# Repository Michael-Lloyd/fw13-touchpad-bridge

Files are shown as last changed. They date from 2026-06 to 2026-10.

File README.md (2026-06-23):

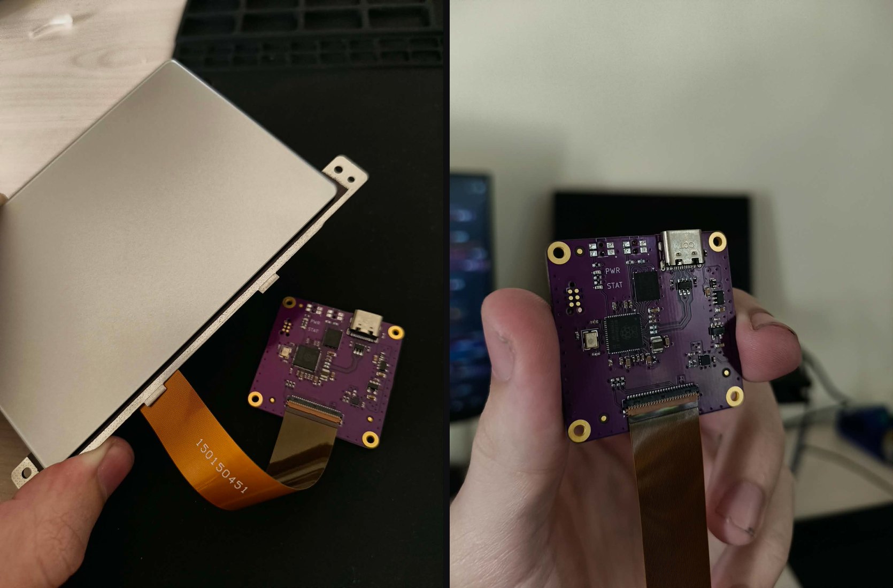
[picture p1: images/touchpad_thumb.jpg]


# Framework 13 Touchpad to USB bridge

Demo video can be found [here](https://youtu.be/qEcvwA03GHM?si=J2vbeN7p9iwUP8ut)

## Hardware files

You can find all of the hardware files under `hardware/` including the the gerbers, drill files and CSV that can be imported into Digikey carts. 

I've done everything in KiCAD, which is free on most systems. 

## Firmware 

The firmware is under `firmware/` and can be built using the Raspberry Pi pico-sdk toolchain. 

If you have any questions or want to talk to me about this project, you can contact me using one of the methods on my website at [micl.dev](https://micl.dev)

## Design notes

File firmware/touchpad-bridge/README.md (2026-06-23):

# Touchpad bridge/adapter firmware

This contains the firmware for the framework 13 touchpad bridge/adapter. The touchpad uses a PixArt PCT3854 HID-over-I2C IC, the report descriptors and feature reports can be passed transparently (including the Microsoft certification blob) unchanged. 

To use this firmware you will need access to the BC-TPI-* board and an appropriately selected 0.3mm pitch ribbon FPC cable to use with it. 

## Building

Requires the pico SDK, an appropriate compile (i.e `arm-none-eabi-gcc`), `cmake`, `ninja` and `picotool` for interacting with the microcontroller. 

To build the binary: 

```bash
# Make sure PICO_SDK_PATH is set 
cmake -B build -G Ninja 
cmake --build build
```

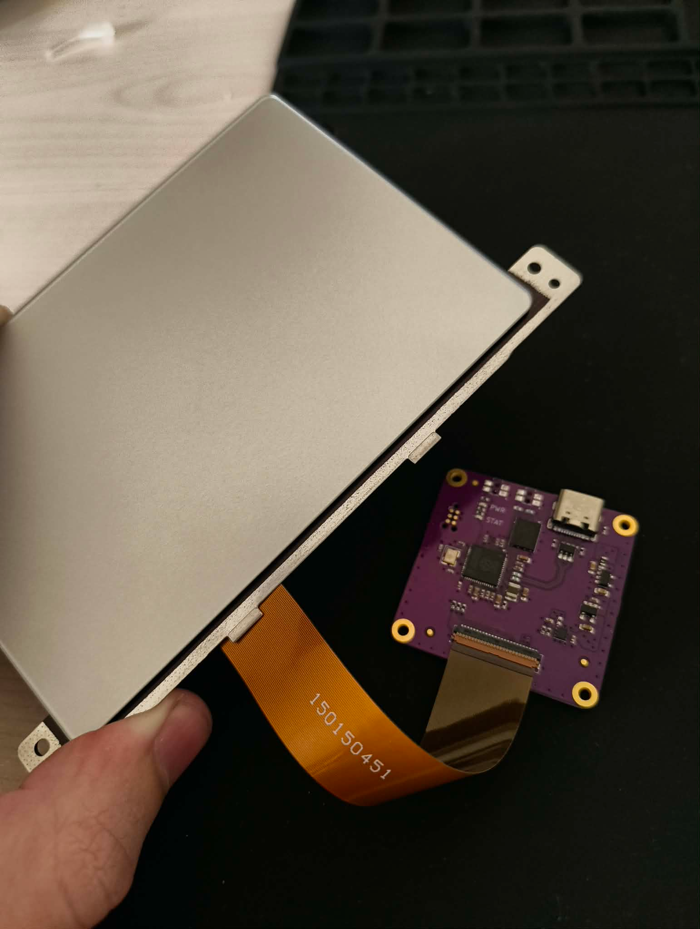
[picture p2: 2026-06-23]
images/touchpad_plugged_in.png

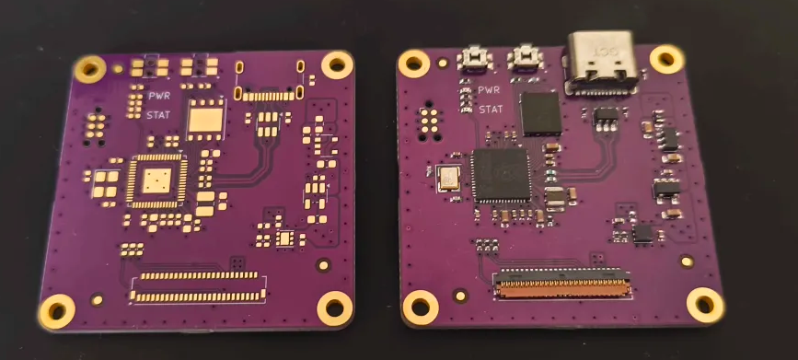
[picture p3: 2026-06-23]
images/gallery17.png

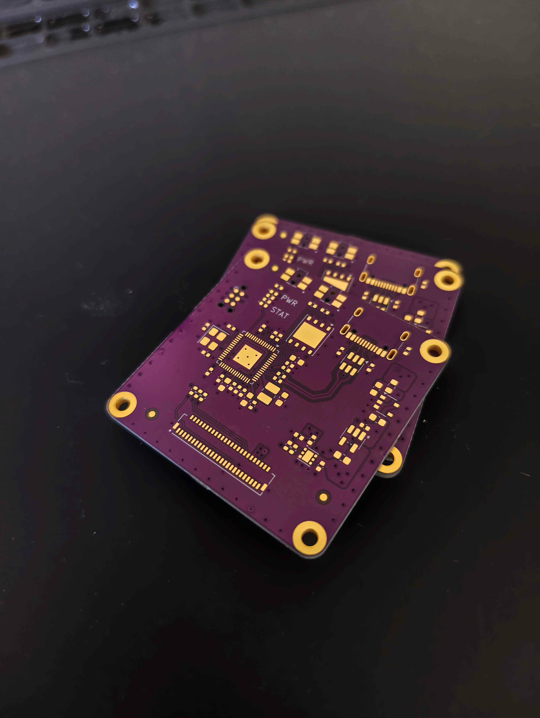
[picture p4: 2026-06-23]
images/gallery18.png

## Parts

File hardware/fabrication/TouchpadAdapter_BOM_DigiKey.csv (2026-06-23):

Digi-Key Part Number | Customer Reference | Quantity
490-10698-1-ND | TP-BRIDGE C1, C5, C7, C8, C9, C10, C11, C13, C14, C15, C16 | 11
490-GRM188Z71A475KE15JCT-ND | TP-BRIDGE C2, C3, C4, C6, C20 | 5
490-5888-1-ND | TP-BRIDGE C17, C18 | 2
490-10017-1-ND | TP-BRIDGE C19, C23, C24 | 3
490-14409-1-ND | TP-BRIDGE C21, C22 | 2
732-13422-1-ND | TP-BRIDGE D1 | 1
732-13424-1-ND | TP-BRIDGE D2 | 1
F5760CT-ND | TP-BRIDGE F1 | 1
490-4002-1-ND | TP-BRIDGE FB1 | 1
445-TFM252012ALVA3R3MTAACT-ND | TP-BRIDGE L1 | 1
2151-RH100-12.000-12-1010-X-TR-NS2CT-ND | TP-BRIDGE Y1 | 1
2019-RK73H1ERTTP1002FCT-ND | TP-BRIDGE R1 | 1
P2.20KLCT-ND | TP-BRIDGE R2, R11 | 2
P4.70KLCT-ND | TP-BRIDGE R3 | 1
P1.00KLCT-ND | TP-BRIDGE R4, R10, R15, R16 | 4
P33.0LCT-ND | TP-BRIDGE R5 | 1
2019-RK73H1ETTP27R0FCT-ND | TP-BRIDGE R6, R7 | 2
P5.10KLCT-ND | TP-BRIDGE R8, R9 | 2
P0.0JCT-ND | TP-BRIDGE R12 | 1
541-100KLCT-ND | TP-BRIDGE R13, R14 | 2
P16765CT-ND | TP-BRIDGE SW1, SW2 | 2
H125806CT-ND | TP-BRIDGE J1 | 1
2073-USB4105-GF-ACT-ND | TP-BRIDGE J3 | 1
2648-SC1509-A4CT-ND | TP-BRIDGE U1 | 1
256-W25Q128JVPIQ-TUBE-ND | TP-BRIDGE U2 | 1
296-TPS7A2033PDBVRCT-ND | TP-BRIDGE U3 | 1
497-11882-1-ND | TP-BRIDGE U4 | 1
NCP361SNT1GOSCT-ND | TP-BRIDGE U5 | 1
296-TLV75901PDRVRCT-ND | TP-BRIDGE U6 | 1
WM21809-ND | TP-BRIDGE CABLE | 1

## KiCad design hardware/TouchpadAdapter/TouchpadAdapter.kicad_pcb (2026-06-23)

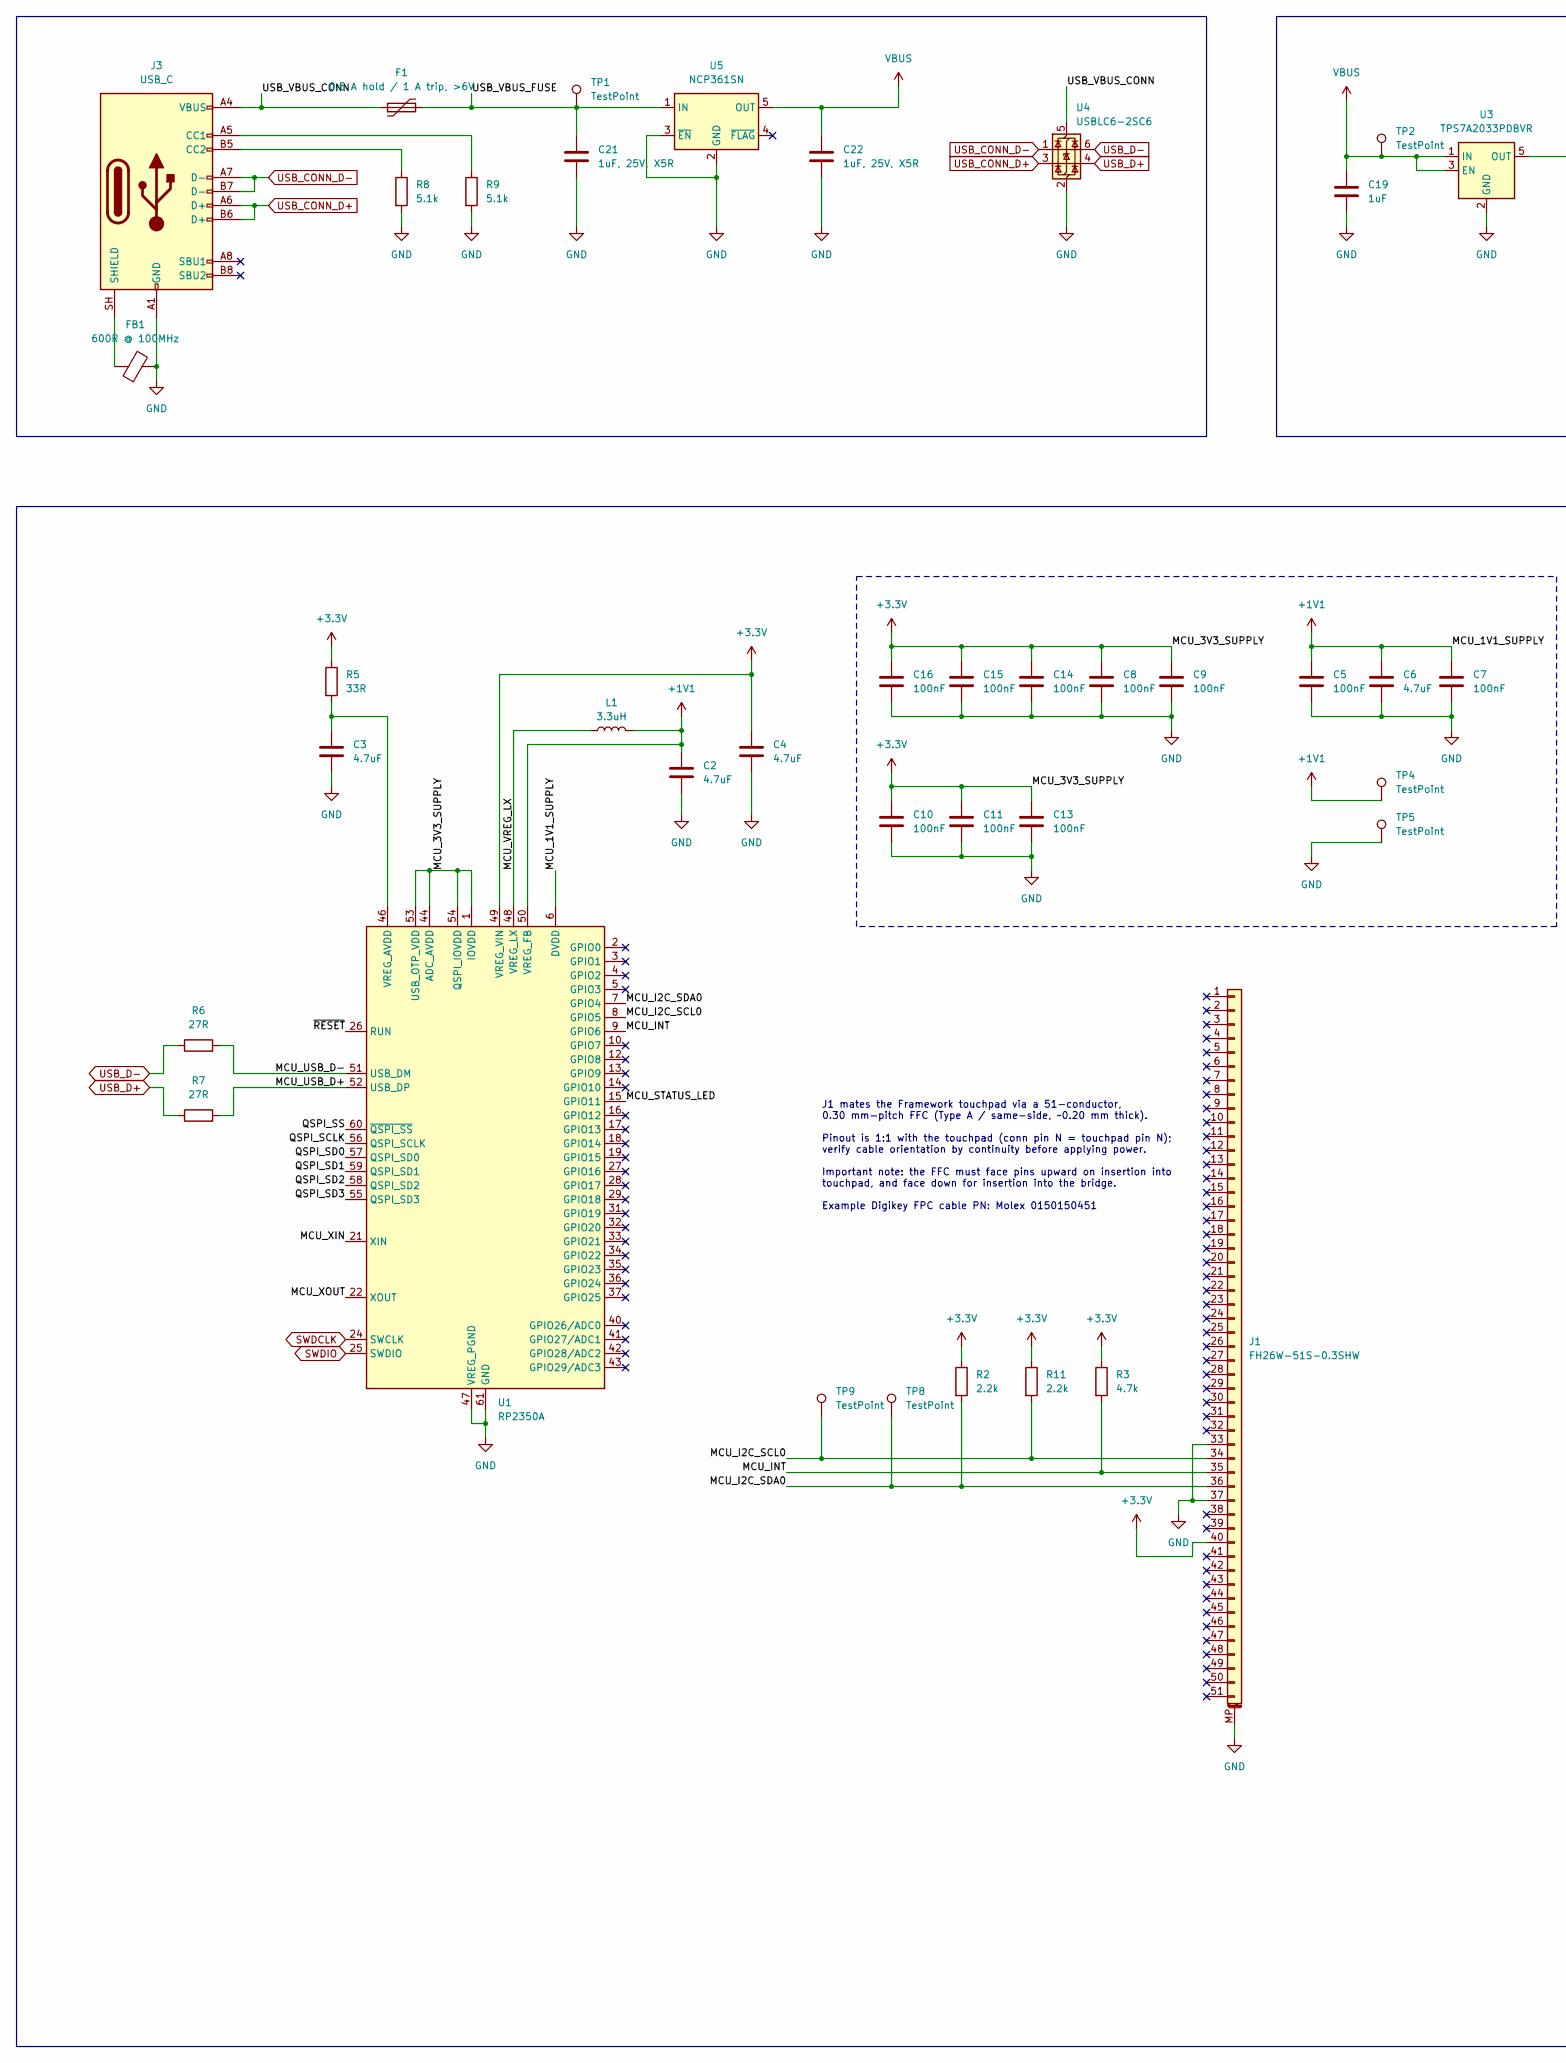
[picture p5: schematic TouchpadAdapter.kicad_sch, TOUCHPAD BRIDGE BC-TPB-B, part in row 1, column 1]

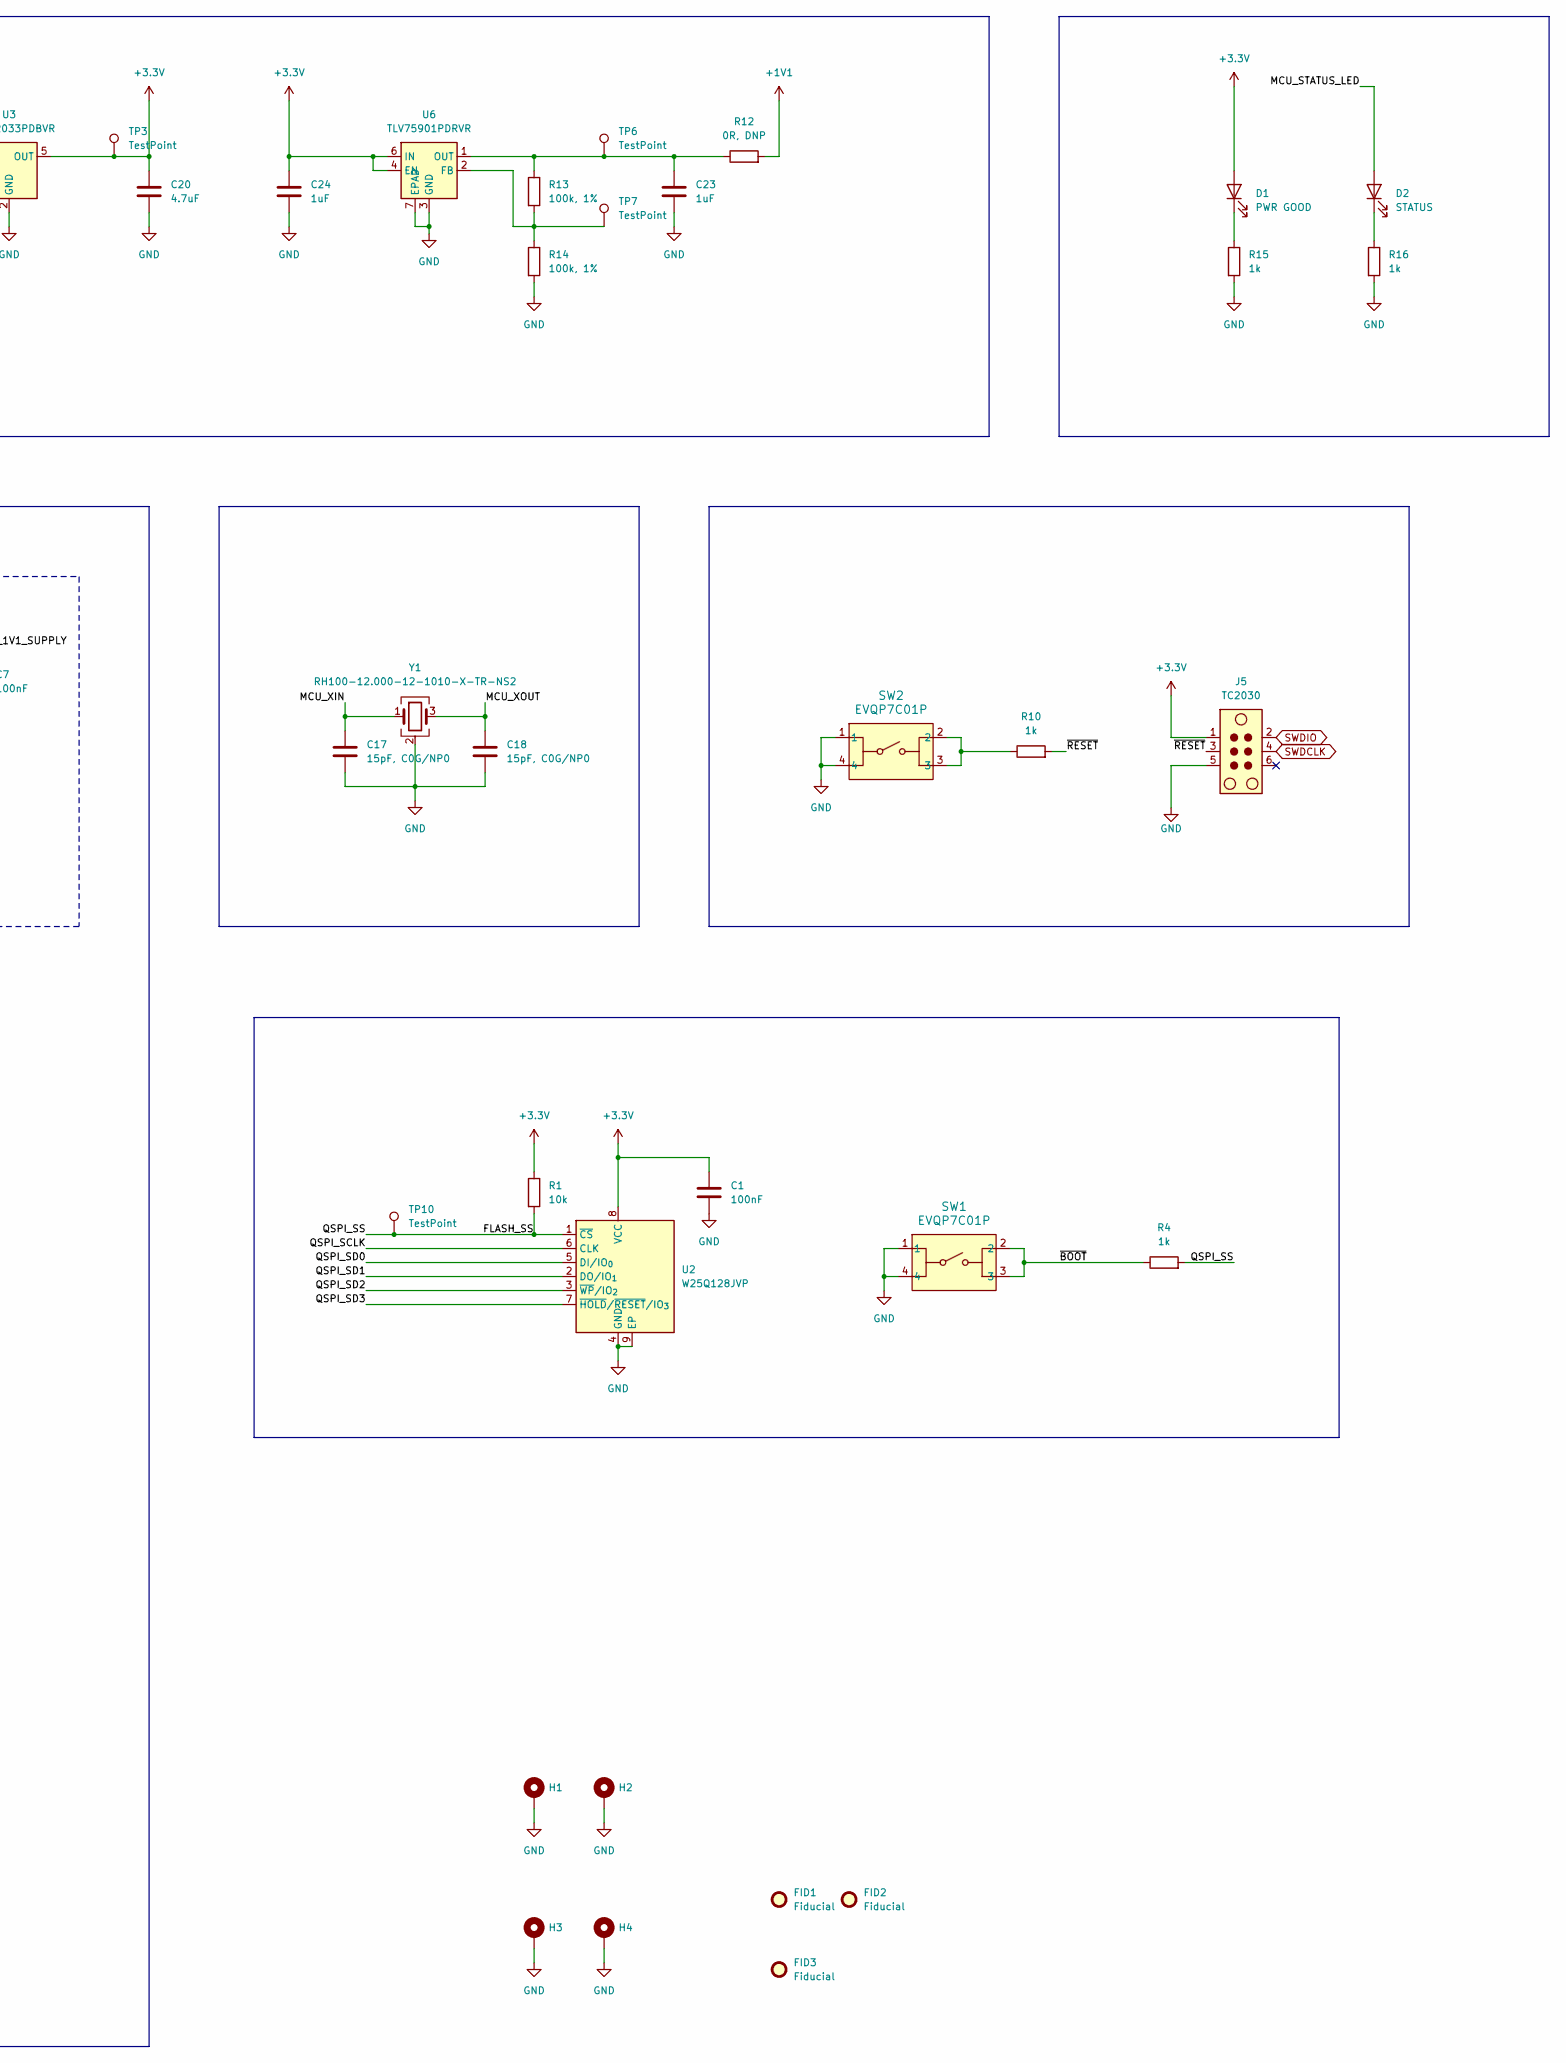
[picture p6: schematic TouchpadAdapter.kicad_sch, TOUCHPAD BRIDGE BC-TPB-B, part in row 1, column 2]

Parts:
C1, C5, C7, C8, C9, C10, C11, C13, C14, C15, C16: 100nF; C_0402_1005Metric; Digikey_MPN GRM155R71E104KE14D
C2, C3, C4, C6, C20: 4.7uF; C_0603_1608Metric; Digikey_MPN GRM188Z71A475KE15J
C17, C18: 15pF, C0G/NP0; C_0402_1005Metric; Digikey_MPN GRM1555C1H150JA01D
C19, C23, C24: 1uF; C_0402_1005Metric; Digikey_MPN GRM155R61E105KA12D
C21, C22: 1uF, 25V, X5R; C_0603_1608Metric; Digikey_MPN GRT188R71E105KE13J
D1: PWR GOOD; LED_0402_1005Metric; Digikey_MPN 150040RS73220
D2: STATUS; LED_0402_1005Metric; Digikey_MPN 150040YS73220
F1: 0.5 A hold / 1 A trip, >6V; R_0603_1608Metric; Digikey_MPN 0603L050SLYR
FB1: 600R @ 100MHz; R_0402_1005Metric; Digikey_MPN BLM15HD601SN1D
FID1, FID2, FID3: Fiducial; Fiducial_1mm_Mask2mm
H1, H2, H3, H4: MountingHole_Pad; MountingHole_2.2mm_M2_Pad
J1: FH26W-51S-0.3SHW; FH26W-51S-0.3SHW60; Digikey_MPN FH26W-51S-0.3SHW(60)
J3: USB_C; USB_C_Receptacle_GCT_USB4105-xx-A_16P_TopMnt_Horizontal
J5: TC2030; Tag-Connect_TC2030-IDC-NL_2x03_P1.27mm_Vertical; Digikey_MPN TC2030-IDC-NL
L1: 3.3uH; L_1008_2520Metric; Digikey_MPN TFM252012ALVA3R3MTAA
R1: 10k; R_0402_1005Metric; Digikey_MPN ERJ-2RKF1002X
R2, R11: 2.2k; R_0402_1005Metric; Digikey_MPN ERJ-2RKF2201X
R3: 4.7k; R_0402_1005Metric; Digikey_MPN ERJ-2RKF4701X
R4, R10, R15, R16: 1k; R_0402_1005Metric; Digikey_MPN ERJ-2RKF1001X
R5: 33R; R_0402_1005Metric; Digikey_MPN ERJ-2RKF33R0X
R6, R7: 27R; R_0402_1005Metric; Digikey_MPN ERJ-2RKF27R0X
R8, R9: 5.1k; R_0402_1005Metric; Digikey_MPN ERJ-2RKF5101X
R12: 0R, DNP; R_0402_1005Metric; Digikey_MPN ERJ-2GE0R00X
R13, R14: 100k, 1%; R_0402_1005Metric; Digikey_MPN CRCW0402100KFKED
SW1, SW2: EVQP7C01P; Digikey_MPN EVQ-P7C01P
TP1, TP2, TP3, TP4, TP5, TP6, TP7, TP8, TP9, TP10: TestPoint; TestPoint_Pad_D0.5mm
U1: RP2350A; QFN-60-1EP_7x7mm_P0.4mm_EP3.4x3.4mm; Digikey_MPN RP2350A
U2: W25Q128JVP; WSON-8-1EP_6x5mm_P1.27mm_EP3.4x4.3mm; Digikey_MPN W25Q128JVPIQ
U3: TPS7A2033PDBVR; SOT-23-5; Digikey_MPN TPS7A2033PDBVR
U4: USBLC6-2SC6; SOT-23-6; Digikey_MPN USBLC6-2SC6Y
U5: NCP361SN; TSOP-5_1.65x3.05mm_P0.95mm; Digikey_MPN NCP361SNT1G
U6: TLV75901PDRVR; WSON-6-1EP_2x2mm_P0.65mm_EP1x1.6mm; Digikey_MPN TLV75901PDRVR
Y1: RH100-12.000-12-1010-X-TR-NS2; Crystal_SMD_3225-4Pin_3.2x2.5mm; Digikey_MPN RH100-12.000-12-1010-X-TR-NS2

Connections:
+1V1: C2.1, C5.1, C6.1, C7.1, L1.2, R12.2, TP4.1 (1_1), U1.6 (DVDD), U1.23 (DVDD), U1.39 (DVDD), U1.50 (VREG_FB)
+3.3V: C1.1, C4.1, C8.1, C9.1, C10.1, C11.1, C13.1, C14.1, C15.1, C16.1, C20.1, C24.1, D1.2 (A), J1.40, J5.1, R1.1, R2.1, R3.1, R5.1, R11.1, TP3.1 (1_1), U1.1 (IOVDD), U1.11 (IOVDD), U1.20 (IOVDD), U1.30 (IOVDD), U1.38 (IOVDD), U1.44 (ADC_AVDD), U1.45 (IOVDD), U1.49 (VREG_VIN), U1.53 (USB_OTP_VDD), U1.54 (QSPI_IOVDD), U2.8 (VCC), U3.5 (OUT), U6.4 (EN), U6.6 (IN)
/FLASH_SS: R1.2, R4.2, TP10.1 (1_1), U1.60 (~QSPI_SS), U2.1 (~CS)
/MCU_I2C_SCL0: J1.34, R11.2, TP9.1 (1_1), U1.8 (GPIO5)
/MCU_I2C_SDA0: J1.36, R2.2, TP8.1 (1_1), U1.7 (GPIO4)
/MCU_INT: J1.35, R3.2, U1.9 (GPIO6)
/MCU_STATUS_LED: D2.2 (A), U1.15 (GPIO11)
/MCU_USB_D+: R7.2, U1.52 (USB_DP)
/MCU_USB_D-: R6.2, U1.51 (USB_DM)
/MCU_VREG_LX: L1.1, U1.48 (VREG_LX)
/MCU_XIN: C17.1, U1.21 (XIN), Y1.1
/MCU_XOUT: C18.1, U1.22 (XOUT), Y1.3
/QSPI_SCLK: U1.56 (QSPI_SCLK), U2.6 (CLK)
/QSPI_SD0: U1.57 (QSPI_SD0), U2.5 (DI/IO_{0})
/QSPI_SD1: U1.59 (QSPI_SD1), U2.2 (DO/IO_{1})
/QSPI_SD2: U1.58 (QSPI_SD2), U2.3 (~WP/IO_{2})
/QSPI_SD3: U1.55 (QSPI_SD3), U2.7 (~HOLD/~RESET/IO_{3})
/USB_VBUS_CONN: F1.1, J3.A4 (VBUS), J3.A9 (VBUS), J3.B4 (VBUS), J3.B9 (VBUS), U4.5 (VBUS)
/USB_VBUS_FUSE: C21.1, F1.2, TP1.1 (1_1), U5.1 (IN)
/~BOOT: R4.1, SW1.2, SW1.3
/~RESET: J5.3, R10.2, U1.26 (RUN)
GND: C1.2, C2.2, C3.2, C4.2, C5.2, C6.2, C7.2, C8.2, C9.2, C10.2, C11.2, C13.2, C14.2, C15.2, C16.2, C17.2, C18.2, C19.2, C20.2, C21.2, C22.2, C23.2, C24.2, FB1.2, H1.1 (1_1), H2.1 (1_1), H3.1 (1_1), H4.1 (1_1), J1.33, J1.37, J1.MP (MountPin), J3.A1 (GND), J3.A12 (GND), J3.B1 (GND), J3.B12 (GND), J5.5, R8.2, R9.2, R14.2, R15.2, R16.2, SW1.1, SW1.4, SW2.1, SW2.4, TP5.1 (1_1), U1.47 (VREG_PGND), U1.61 (GND), U2.4 (GND), U2.9 (EP), U3.2 (GND), U4.2 (GND), U5.2 (GND), U5.3 (~EN), U6.3 (GND), U6.7 (EPAD), Y1.2 (G), Y1.4 (G)
unnamed: D1.1 (K), R15.1
unnamed: D2.1 (K), R16.1
unnamed: J3.A5 (CC1), R9.1
unnamed: J3.B5 (CC2), R8.1
unnamed: FB1.1, J3.SH (SHIELD)
unnamed: R10.1, SW2.2, SW2.3
unnamed: C3.1, R5.2, U1.46 (VREG_AVDD)
unnamed: R13.2, R14.1, TP7.1 (1_1), U6.2 (FB)
unnamed: C23.1, R12.1, R13.1, TP6.1 (1_1), U6.1 (OUT)
SWDCLK: J5.4, U1.24 (SWCLK)
SWDIO: J5.2, U1.25 (SWDIO)
USB_CONN_D+: J3.A6 (D+), J3.B6 (D+), U4.3 (I/O2)
USB_CONN_D-: J3.A7 (D-), J3.B7 (D-), U4.1 (I/O1)
USB_D+: R7.1, U4.4 (I/O2)
USB_D-: R6.1, U4.6 (I/O1)
VBUS: C19.1, C22.1, TP2.1 (1_1), U3.1 (IN), U3.3 (EN), U5.5 (OUT)

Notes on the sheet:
J1 mates the Framework touchpad via a 51-conductor, 0.30 mm-pitch FFC (Type A / same-side, ~0.20 mm thick). Pinout is 1:1 with the touchpad (conn pin N = touchpad pin N); verify cable orientation by continuity before applying power. Important note: the FFC must face pins upward on insertion into to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

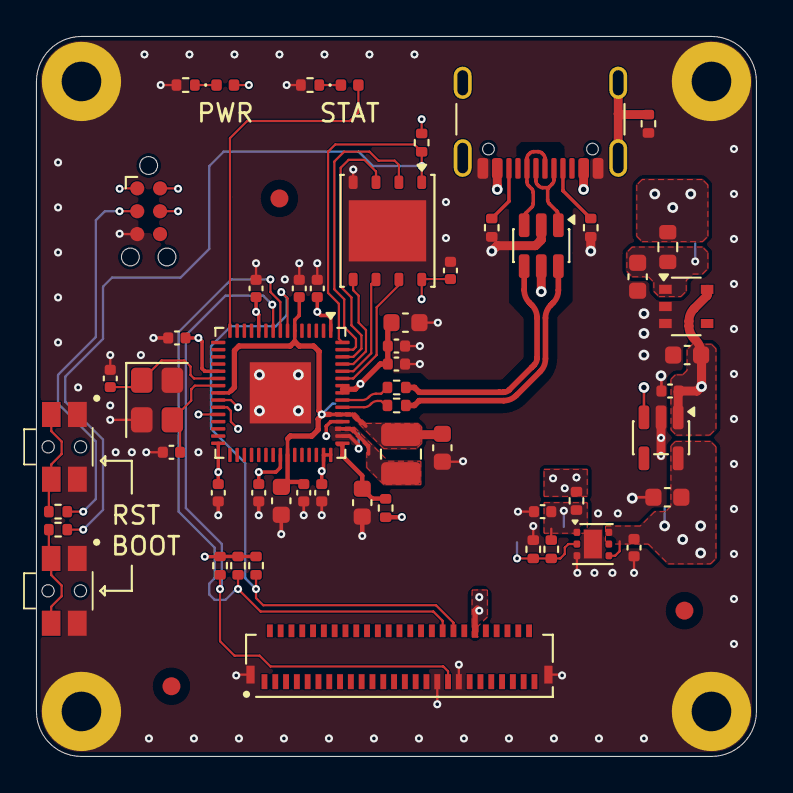
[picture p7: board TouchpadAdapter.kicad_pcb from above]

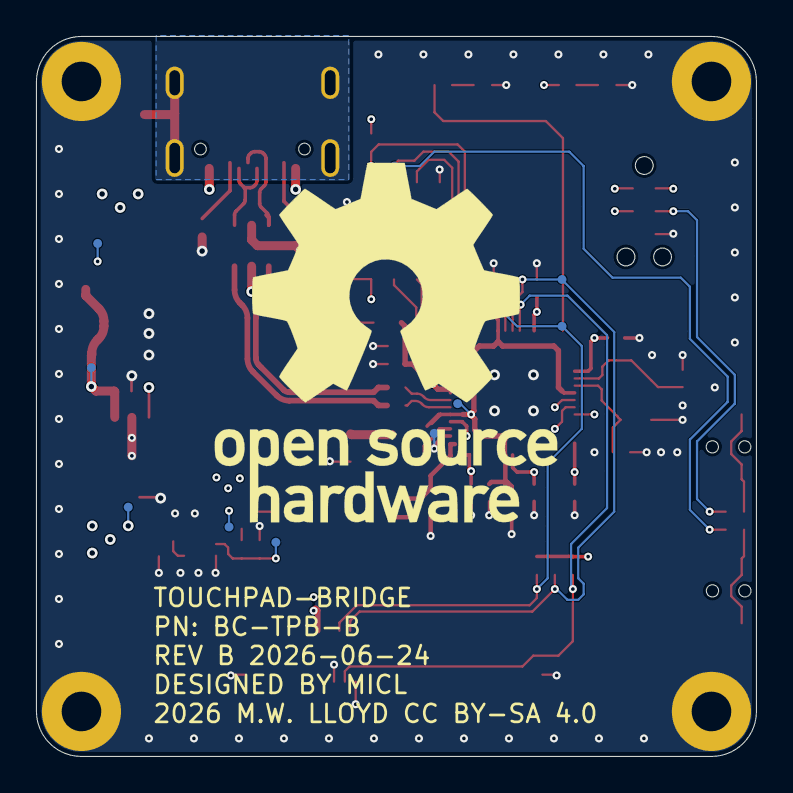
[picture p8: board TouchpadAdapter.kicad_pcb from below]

Board: 4 copper layers, 40.0 x 40.0 mm, 73 parts (10 on the bottom side), 38 nets.

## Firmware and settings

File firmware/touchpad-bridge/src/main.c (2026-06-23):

/*
 * Entry point for the framework touchpad bridge. Brings up the I2C-HID
 * host link to the touchpad, then starts the USB device stack and
 * relays input reports across the bridge.
 *
 * SPDX-License-Identifier: GPL-3.0-or-later
 * Copyright (C) 2026 Michael Lloyd
 */

#include <pico/stdlib.h>
#include <tusb.h>

#include <status.h>
#include <touchpad.h>

int main(void) {
    stdio_init_all();
    status_init();

    status_set(STATUS_ERROR);
    while (touchpad_init() != 0) {
        status_task();
        sleep_ms(250);
    }

    status_set(STATUS_WAIT);
    tusb_init();

    while (true) {
        // service USB events
        tud_task(); 
        // forward pending touchpad input reports
        touchpad_task();    

        // Solid once the host enumerates us; slow blink while waiting.
        status_set(tud_mounted() ? STATUS_OK : STATUS_WAIT);
        status_task();
    }
}

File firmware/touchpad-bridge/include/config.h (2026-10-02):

/*
 * board and build configuration for the RP2350A touchpad bridge,
 * for use with the BC-TPI-A bridge board. Modify otherwise 
 *
 * SPDX-License-Identifier: GPL-3.0-or-later
 * Copyright (C) 2026 Michael Lloyd
 */

#ifndef _CONFIG_H_
#define _CONFIG_H_

#include <hardware/i2c.h>

// I2C host link to the Framework touchpad (PixArt PCT3854)
#define TP_I2C_INST         i2c0
#define TP_I2C_SDA_PIN      4
#define TP_I2C_SCL_PIN      5
#define TP_INT_PIN          6
#define TP_I2C_BAUD_HZ      400000
#define TP_I2C_ADDR         0x2c

// I2C HID descriptor register; the pointer at which the device exposes its HID 
// descriptor, found by probing the framework touchpad module. 
// Reverse-engineered by the touchpad-adventure project (MIT), re-derived
// here not copied; Framework's docs omit this register:
//   https://github.com/jeongm-in/touchpad-adventure
#define TP_HID_DESC_REG     0x0020

// status LED D2, active-high
#define TP_LED_PIN          11
// 0 = poll INT level, maybe use 1 = GPIO IRQ
#define TP_USE_INTERRUPT    0
// the PTP report descriptor is 687 bytes 
#define TP_REPORT_DESC_MAX  768         // 687-byte descriptor size from touchpad-adventure
// PTP input report is ~35 bytes 
#define TP_INPUT_REPORT_MAX 64          // ~35-byte report size from touchpad-adventure
// largest feature report is the 256-byte PTPHQA certification blob
#define TP_FEATURE_REPORT_MAX 256

#endif // _CONFIG_H_

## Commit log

2026-06-23 Initial rev b files
    [TouchpadAdapter.kicad_pcb, TouchpadAdapter.kicad_sch, TouchpadAdapter_BOM_DigiKey.csv]
2026-06-23 Firmware and repository release
    [TouchpadAdapter.kicad_pcb, TouchpadAdapter.kicad_sch, TouchpadAdapter_BOM_DigiKey.csv]

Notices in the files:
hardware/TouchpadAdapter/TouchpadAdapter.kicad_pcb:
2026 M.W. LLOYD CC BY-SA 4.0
